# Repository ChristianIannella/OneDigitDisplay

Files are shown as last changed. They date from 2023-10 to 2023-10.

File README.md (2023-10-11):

# OneDigitDisplay
I2C interface for 7 segment LCD

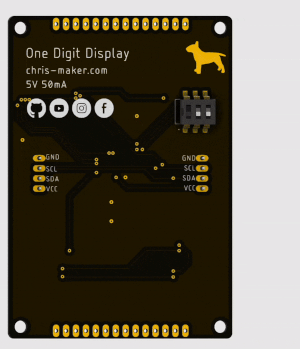
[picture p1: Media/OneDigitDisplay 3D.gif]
OneDigitDisplay Iannella Christian


<picture><picture>

Con One Digit Display puoi controllare [questi](https://github.com/ChristianIannella/OneDigitDisplay/blob/main/Media/7%20segment%20lcd.png) LCD a 7 segmenti dall'aspetto in po' vintage semplicemente con interfaccia I2C, quindi con solo due fili!

Il modulo lavora a 5V. Tramite la porta ICSP è possibile modificare o aggiornare il firmware. Ecco il mio programmatore [ICSP](https://www.tindie.com/products/30806/)

# I2C COMMAND

Ecco la lista completa dei comandi.

| First byte | Second byte | Symbol|
| ---| ---| ---|
|32 | 0 | Space |
|48 |(0 or 1) | 0 |
|49 |(0 or 1) | 1  |
|51 |(0 or 1) | 2 | 
|50 |(0 or 1) | 3|
|52 |(0 or 1) | 4|
|53 |(0 or 1) | 5|
|54 |(0 or 1) | 6|
|55 |(0 or 1) | 7|
|56 |(0 or 1) | 8|
|57 |(0 or 1) | 9|
|10 | 0 | Erase|
|46 | 0 | .|
|45 |(0 or 1) | -|
|20 |(0 or 1) | ˚|
|65 |(0 or 1) | A|
|98 |(0 or 1) | b|
|99 |(0 or 1) | c|
|67 |(0 or 1) | C|
|100 |(0 or 1) | d|
|69 |(0 or 1) | E|
|70 |(0 or 1) | F|
|72 |(0 or 1) | H|
|73 |(0 or 1) | I|
|76 |(0 or 1) | L|
|79 |(0 or 1) | O|
|80 |(0 or 1) | P|
|83 |(0 or 1) | S|
|85 |(0 or 1) | U|
|117 |(0 or 1) | u|
|27 |(0 or 1) |  Segment a|
|28 |(0 or 1) |  Segment b|
|29 |(0 or 1) |  Segment c|
|30 |(0 or 1) |  Segment d|
|31 |(0 or 1) |  Segment e|
|40 |(0 or 1) |  Segment f|
|33 |(0 or 1) |  Segment g|
|34 |(1 to 7) |  DP blink and speed|
|35 |(0 or 1) |  DP stop|
|36 |(0 to 255) |  Background color HSV | 
|37 |(0 to 255) |  Backlight brightness|
|38 |(0 to 255) |  Rainbow effec, default speed 0|
|39 | 0 |  Erase all|

Ogni comando è formato da due Byte, il primo indica la funzione da eseguire e il secondo è un parametro che cambia a seconda della funzione.

Nel di comnadi che stampano caratteri o numeri il parametro puo valere `0`o `1`, `1` attiverà anche il DP `0` no.
I comandi per stampare i caratteri in oltre seguono il codice ASCII.

```
  address = 0
  command[0] = 65;
  command[1] = 1;
  Wire.beginTransmission(address);
  Wire.write(command, sizeof command);
  Wire.endTransmission();
```

L'esempio sopra stamperà la lettera "A" e accenderà il DP del display con indirizzo 0.

Il comando `10` (`erase`) pulisce il display ma lascia attive le altre fuzioni tiopo retroilluminazione ecc. Non necessita di parametri aggiuntivi.

Il comando `34` (`DP blink`) farà lampeggiare il DP con una velocità compresa tra 100 ms e 2s

|Secon Byte|Velocità|
|---|---|
|0|100ms|
|1|200ms|
|2|300ms|
|3|400ms|
|4|500ms|
|5|1000ms|
|6|1500ms|
|7|2000ms|

Esempio:

```
  address = 0
  command[0] = 34;
  command[1] = 4;
  Wire.beginTransmission(address);
  Wire.write(command, sizeof command);
  Wire.endTransmission();
```

Il comando `35` (`DP stop`) blocca il lampeggio del DP e col secondo Byte si puo' decidere se tenerlo acceso o spento.

Il comando `36` serve per cambiare il colore della retroilluminazone tramite il parametro che va da `0` a `255`

Il comando `37` serve per cambiare la luminosità il parametro che va da `0` a `255`

Il comando `38` (`rainbow`) avvia un effetto di colori casuali che cambiano piu' o meno velocemente in base al secondo Byte. Per interrompere l'effetto basta cambiare colore o con il comando `erase_all`.

Il comando `39` fa quello che fa `erase` ma questa volta blocca anche tutte le funzioni attive come `DP blink` o `rainbow`

Il comando `46` mostra il DP, non necessita di parametri.

# I2C ADDRESS
Per indirizzare il display sul retro ci sono 3 dip switch quindi 8 indirizzi possibili, assicurati di dare l'indirizzo desiderato prima di alimentare la scheda.

Nel caso hai bisogno di cambiare indirizzo assicurati di spegnere e riaccendere la schheda dopo averlo cambiato.

# I2C EXAMPLE

```
#include <Wire.h>

int address = 0;
byte command[2];

void setup()
{
  Wire.begin();
  delay(100);

  command[0] = 39; // Erase All Command 
  command[1] = 0;
  Wire.beginTransmission(address);
  Wire.write(command, sizeof command);
  Wire.endTransmission();

  command[0] = 37; // Rainbow
  command[1] = 50;
  Wire.beginTransmission(address);
  Wire.write(command, sizeof command);
  Wire.endTransmission();  
}

void loop(){
}
```

[Esempio completo](https://github.com/ChristianIannella/OneDigitDisplay/tree/main/Example)

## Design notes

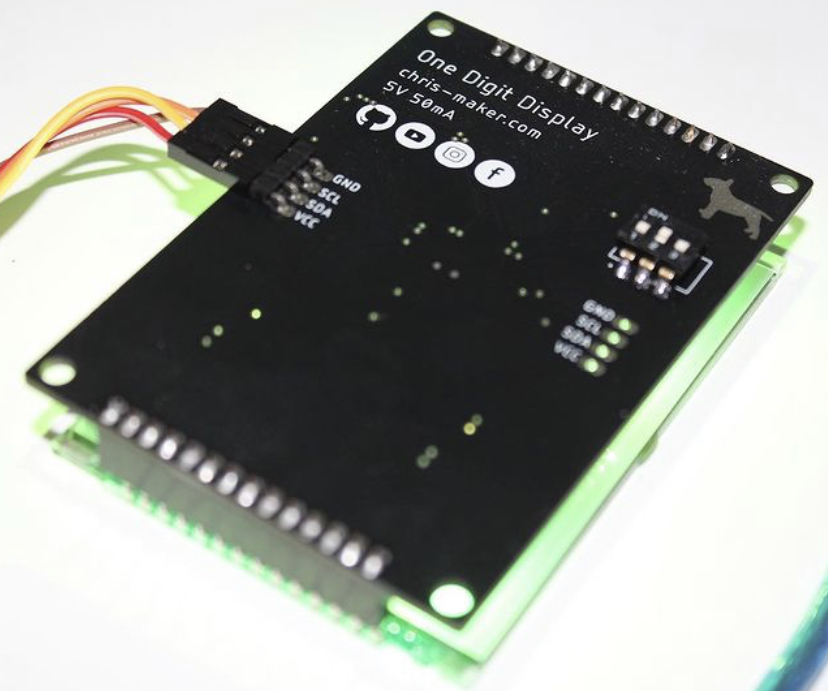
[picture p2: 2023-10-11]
Media/Rear view.jpg

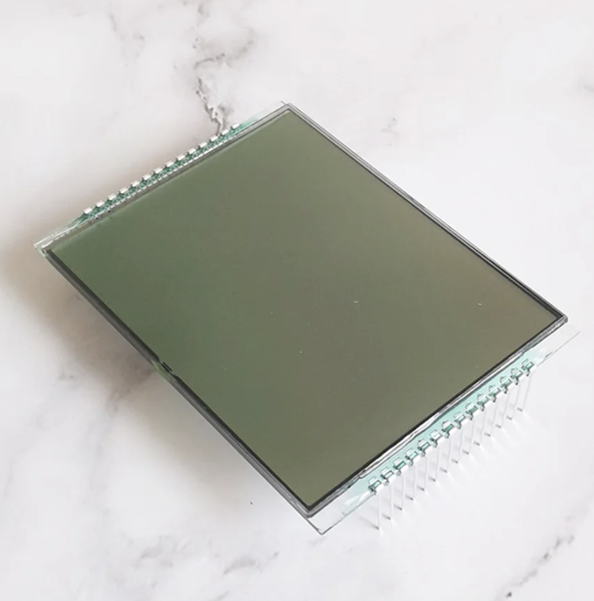
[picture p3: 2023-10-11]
Media/7 segment lcd.png

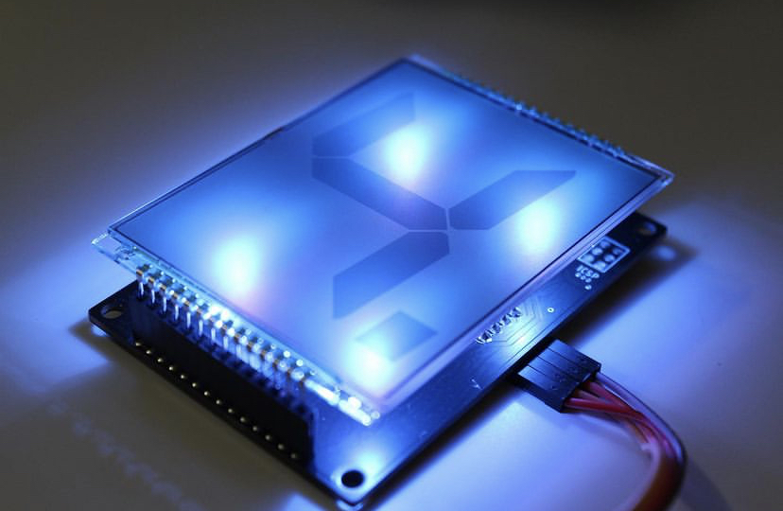
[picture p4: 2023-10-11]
Media/Front view.jpg

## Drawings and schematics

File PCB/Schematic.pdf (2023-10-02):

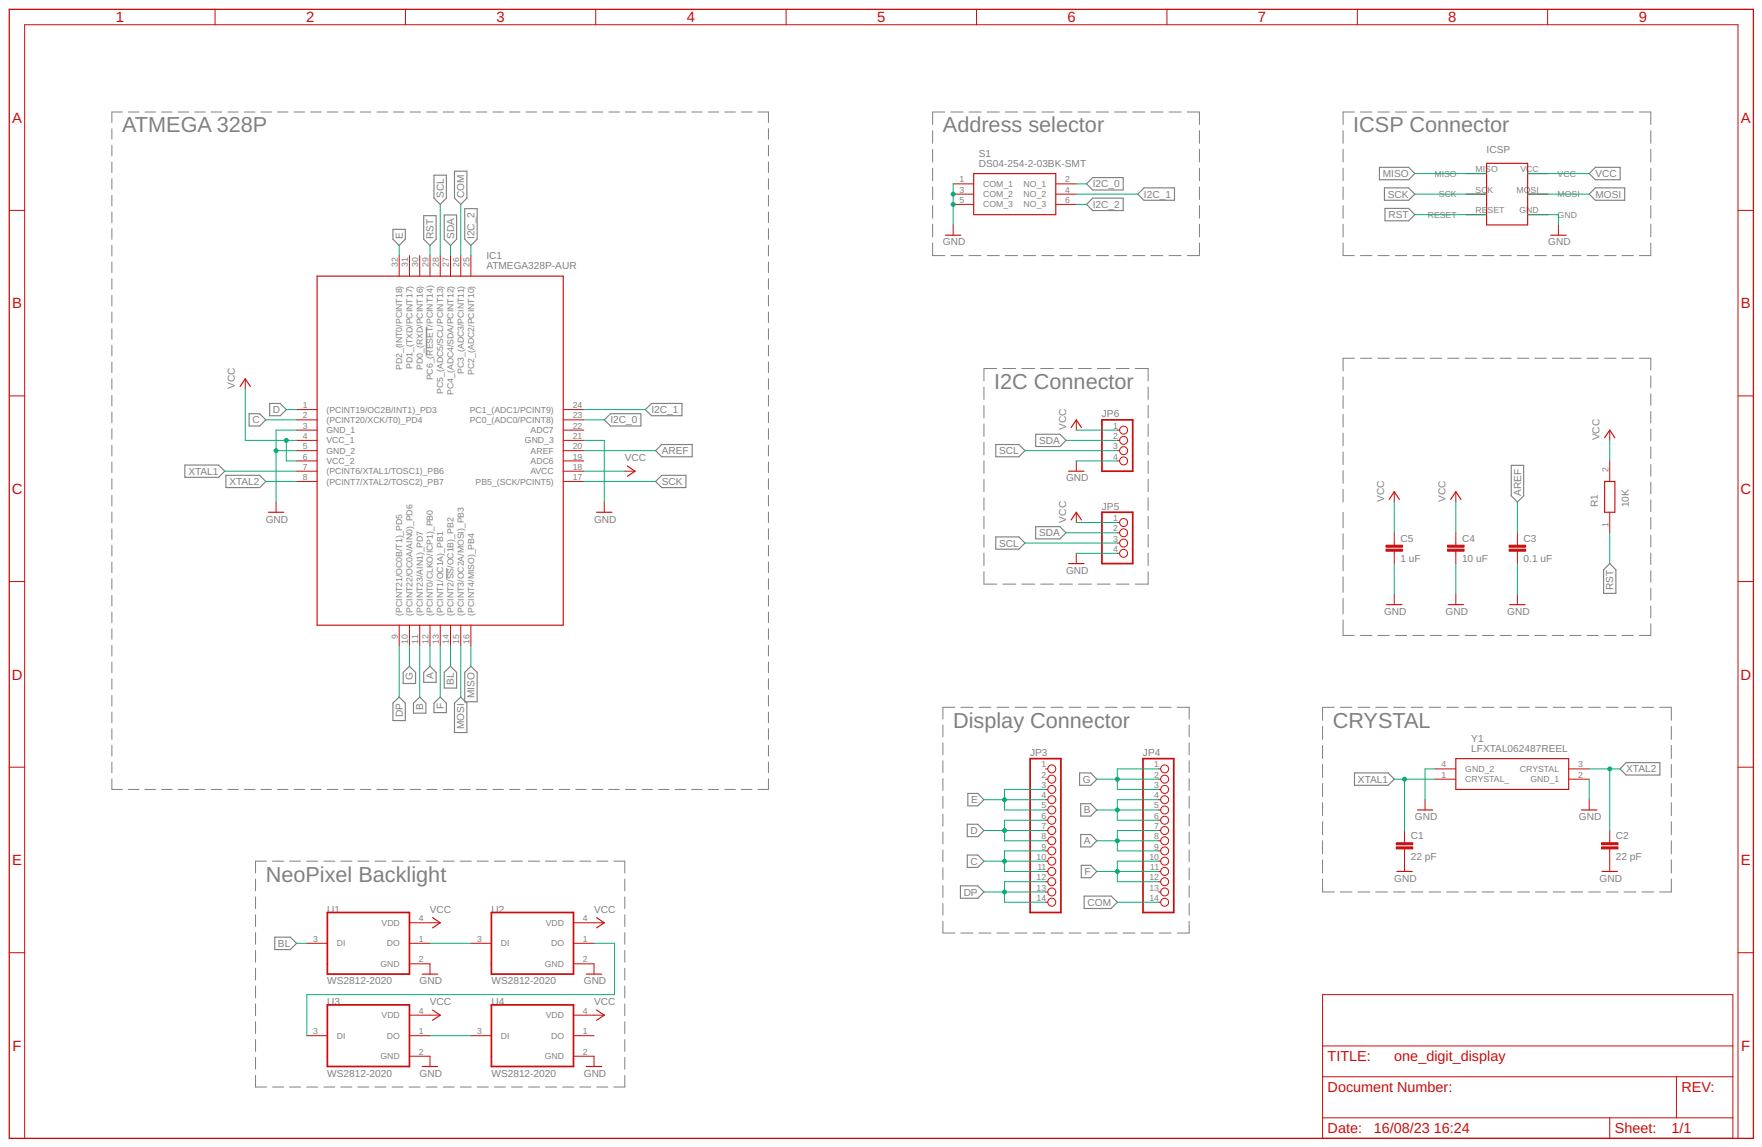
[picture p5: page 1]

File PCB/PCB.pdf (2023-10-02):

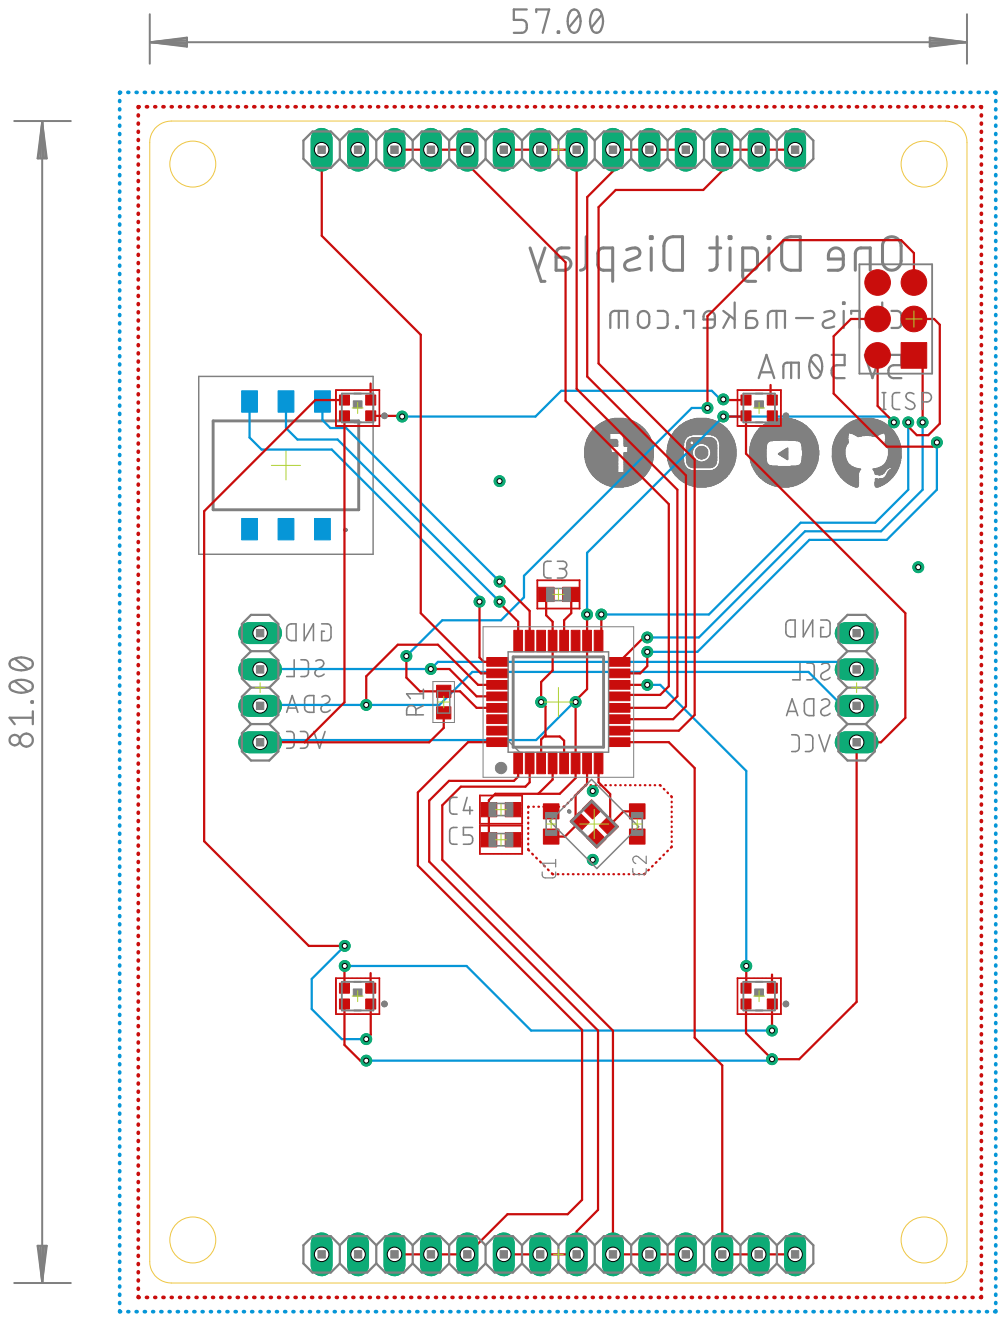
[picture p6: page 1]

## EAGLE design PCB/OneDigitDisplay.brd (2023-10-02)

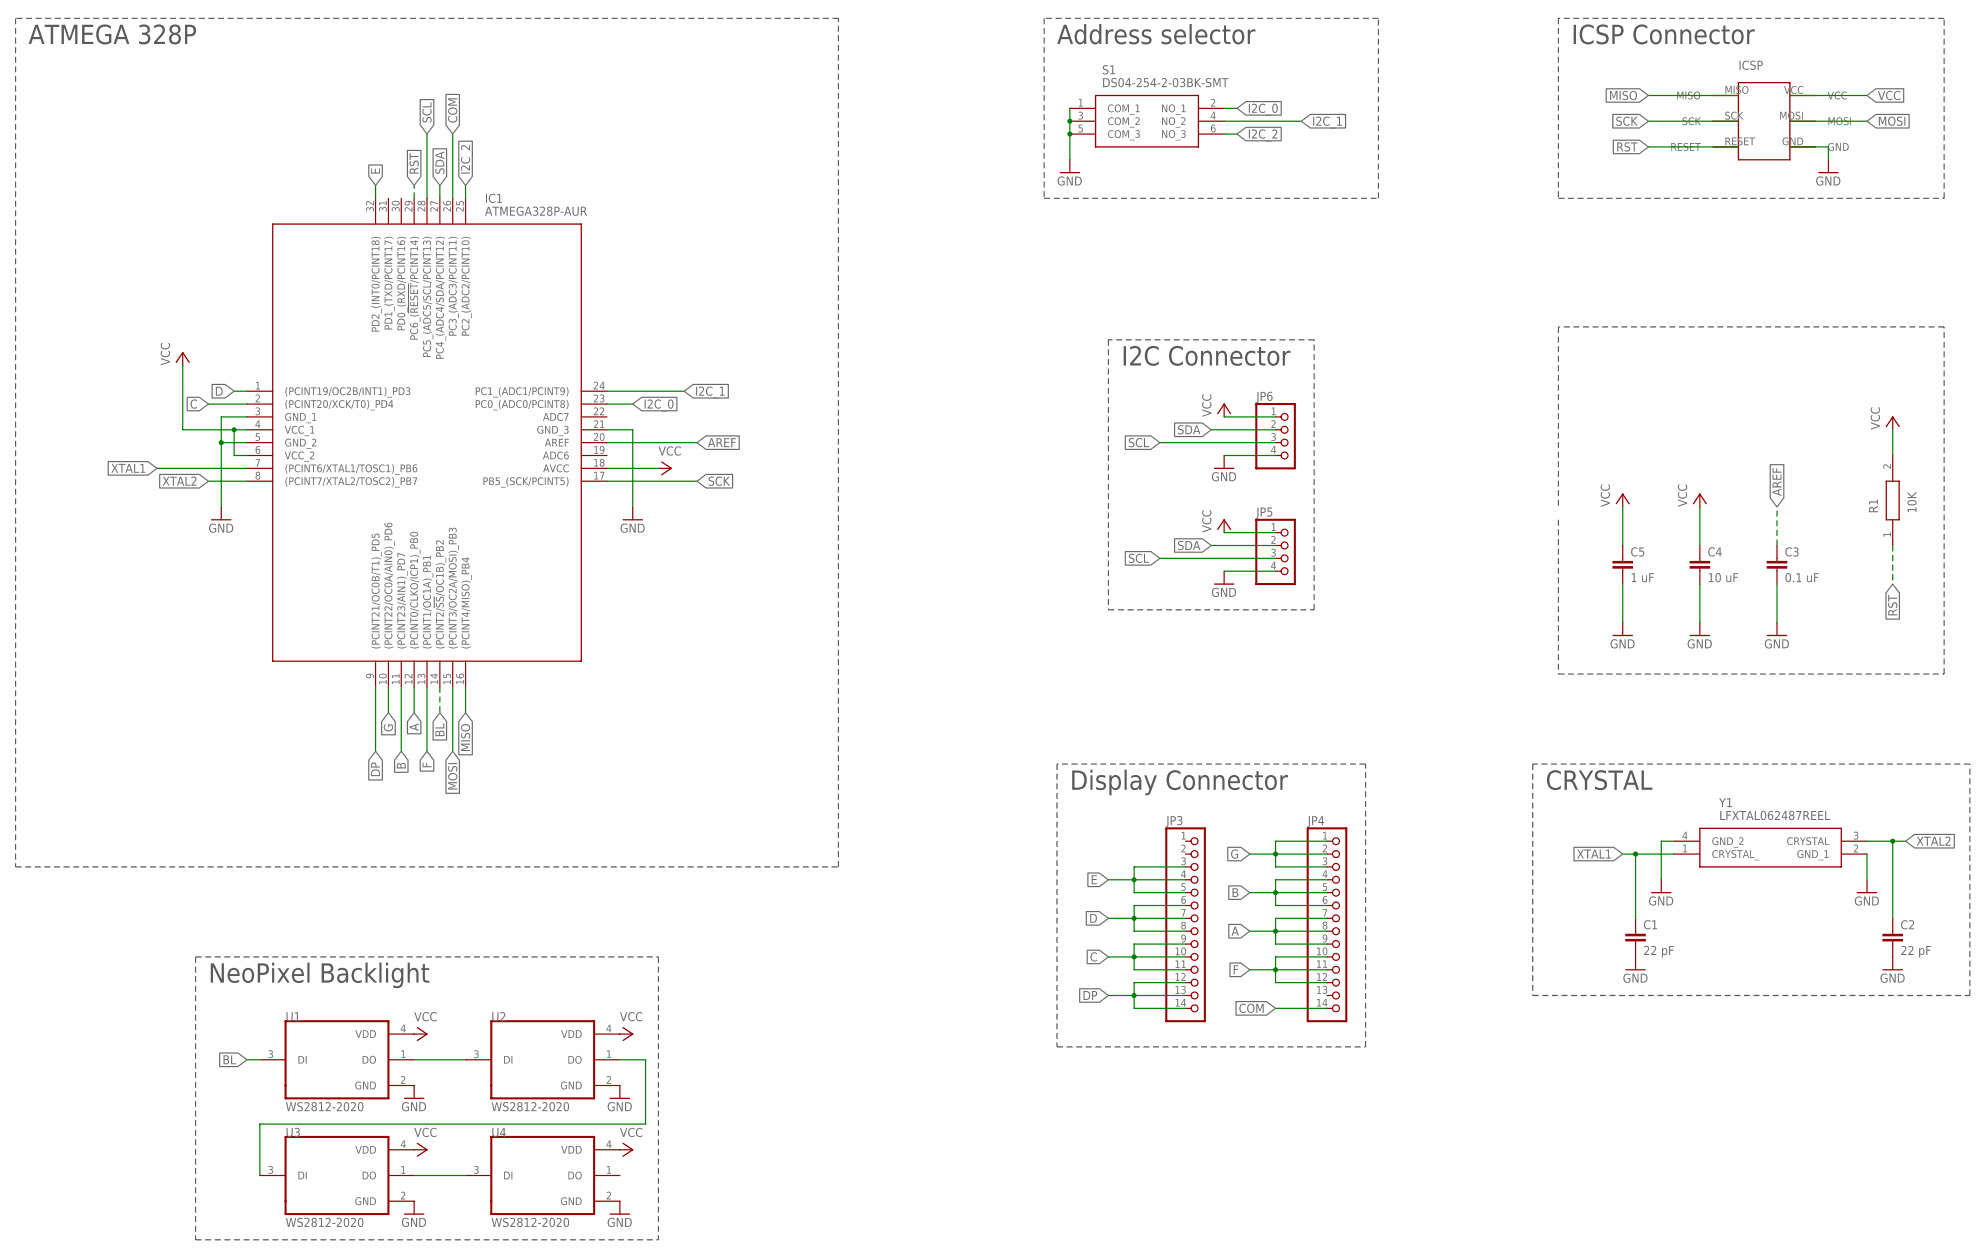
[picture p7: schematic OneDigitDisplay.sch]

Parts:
C1, C2: 22 pF; C0603K
C3: 0.1 uF; C0603
C4: 10 uF; C0603
C5: 1 uF; C0603
IC1: ATMEGA328P-AUR; QFP80P900X900X120-32N
JP3, JP4: PINHD-1X14; 1X14
JP5, JP6: PINHD-1X4; 1X04
R1: 10K; RESC1608X55N
S1: DS04-254-2-03BK-SMT; DS04254203BKSMT
U1, U2, U3, U4: WS2812-2020; LED_WS2812-2020
U$1: 6PINICSP
Y1: LFXTAL062487REEL

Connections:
A: IC1.12 ((PCINT0/CLKO/ICP1)_PB0), JP4.7, JP4.8, JP4.9
AREF: C3.1, IC1.20 (AREF)
B: IC1.11 ((PCINT23/AIN1)_PD7), JP4.4, JP4.5, JP4.6
BL: IC1.14 ((PCINT2/!SS!/OC1B)_PB2), U1.3 (DI)
C: IC1.2 ((PCINT20/XCK/T0)_PD4), JP3.9, JP3.10, JP3.11
COM: IC1.26 (PC3_(ADC3/PCINT11)), JP4.14
D: IC1.1 ((PCINT19/OC2B/INT1)_PD3), JP3.6, JP3.7, JP3.8
DP: IC1.9 ((PCINT21/OC0B/T1)_PD5), JP3.12, JP3.13, JP3.14
E: IC1.32 (PD2_(INT0/PCINT18)), JP3.3, JP3.4, JP3.5
F: IC1.13 ((PCINT1/OC1A)_PB1), JP4.10, JP4.11, JP4.12
G: IC1.10 ((PCINT22/OC0A/AIN0)_PD6), JP4.1, JP4.2, JP4.3
GND: C1.2, C2.2, C3.2, C4.2, C5.2, IC1.3 (GND_1), IC1.5 (GND_2), IC1.21 (GND_3), JP5.4, JP6.4, S1.1 (COM_1), S1.3 (COM_2), S1.5 (COM_3), U1.2 (GND), U2.2 (GND), U3.2 (GND), U4.2 (GND), U$1.GND, Y1.2 (GND_1), Y1.4 (GND_2)
I2C_0: IC1.23 (PC0_(ADC0/PCINT8)), S1.2 (NO_1)
I2C_1: IC1.24 (PC1_(ADC1/PCINT9)), S1.4 (NO_2)
I2C_2: IC1.25 (PC2_(ADC2/PCINT10)), S1.6 (NO_3)
MISO: IC1.16 ((PCINT4/MISO)_PB4), U$1.MISO
MOSI: IC1.15 ((PCINT3/OC2A/MOSI)_PB3), U$1.MOSI
unnamed: U1.1 (DO), U2.3 (DI)
unnamed: U2.1 (DO), U3.3 (DI)
unnamed: U3.1 (DO), U4.3 (DI)
RST: IC1.29 (PC6_(!RESET!/PCINT14)), R1.1, U$1.RESET
SCK: IC1.17 (PB5_(SCK/PCINT5)), U$1.SCK
SCL: IC1.28 (PC5_(ADC5/SCL/PCINT13)), JP5.3, JP6.3
SDA: IC1.27 (PC4_(ADC4/SDA/PCINT12)), JP5.2, JP6.2
VCC: C4.1, C5.1, IC1.4 (VCC_1), IC1.6 (VCC_2), IC1.18 (AVCC), JP5.1, JP6.1, R1.2, U1.4 (VDD), U2.4 (VDD), U3.4 (VDD), U4.4 (VDD), U$1.VCC
XTAL1: C1.1, IC1.7 ((PCINT6/XTAL1/TOSC1)_PB6), Y1.1 (CRYSTAL_)
XTAL2: C2.1, IC1.8 ((PCINT7/XTAL2/TOSC2)_PB7), Y1.3 (CRYSTAL)

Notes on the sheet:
CRYSTAL
NeoPixel Backlight
Address selector
ICSP Connector
Display Connector
I2C Connector
ATMEGA 328P

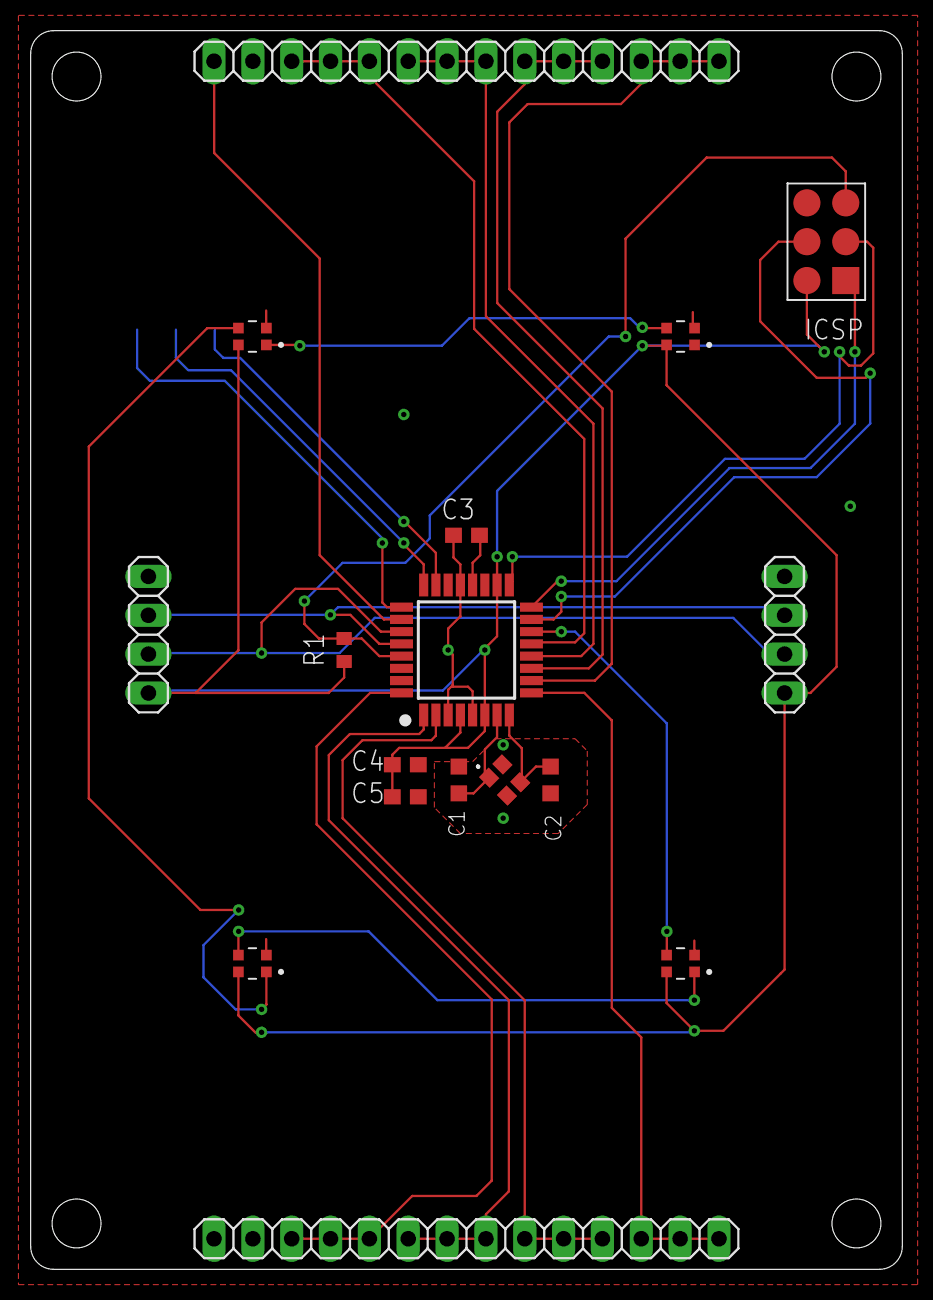
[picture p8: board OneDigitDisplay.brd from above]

Board: 2 copper layers, 57.0 x 81.0 mm, 18 parts (1 on the bottom side), 27 nets.

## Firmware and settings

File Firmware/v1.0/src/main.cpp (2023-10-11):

#include <Arduino.h>
#include <Wire.h>
#include <Adafruit_NeoPixel.h>

#define LED_PIN 10
#define NUM_LED 4
Adafruit_NeoPixel pixel = Adafruit_NeoPixel(NUM_LED, LED_PIN, NEO_GRB + NEO_KHZ800);

#define E 2
#define D 3
#define C 4
#define DP 5
#define G 6
#define B 7
#define A 8
#define F 9
#define COM A3
#define b_l 10
#define DS0 A2
#define DS1 A1
#define DS2 A0

int input_pin[3] = {DS0, DS1, DS2};
byte i2c_address_input[3] = {0};
int i2c_address = 0;

unsigned long previous = 0;
unsigned long previous_dp_blink = 0;
long firstPixelHue = 0;
unsigned long t = 0;

int b_l_value = 0;
bool state = false;
bool dp_blynk_state = false;
unsigned long dp_delay = 20;
bool dp = false;
bool rainbow_state = false;
int rainbow_speed = 0;
int digit = 10;

//                      First byte  Second byte     Symbol
void print_space();     // 32             x          space
void print_zero();      // 48          (0 or 1)        0
void print_one();       // 49          (0 or 1)        1
void print_two();       // 50          (0 or 1)        2
void print_three();     // 51          (0 or 1)        3
void print_four();      // 52          (0 or 1)        4
void print_five();      // 53          (0 or 1)        5
void print_six();       // 54          (0 or 1)        6
void print_seven();     // 55          (0 or 1)        7
void print_eight();     // 56          (0 or 1)        8
void print_nine();      // 57          (0 or 1)        9
void erase();           // 10             x
void show_dp();         // 46             x            .
void print_dash();      // 45          (0 or 1)        -
void print_degrees();   // 20          (0 or 1)        ˚
void print_A();         // 65          (0 or 1)        A
void print_b();         // 98          (0 or 1)        b
void print_c();         // 99          (0 or 1)        c
void print_C();         // 67          (0 or 1)        C
void print_d();         // 100         (0 or 1)        d
void print_E();         // 69          (0 or 1)        E
void print_F();         // 70          (0 or 1)        F
void print_H();         // 72          (0 or 1)        H
void print_I();         // 73          (0 or 1)        I
void print_L();         // 76          (0 or 1)        L
void print_O();         // 79          (0 or 1)        O
void print_P();         // 80          (0 or 1)        P
void print_S();         // 83          (0 or 1)        S
void print_U();         // 85          (0 or 1)        U
void print_u();         // 117         (0 or 1)        u
void print_segment_a(); // 27          (0 or 1)
void print_segment_b(); // 28          (0 or 1)
void print_segment_c(); // 29          (0 or 1)
void print_segment_d(); // 30          (0 or 1)
void print_segment_e(); // 31          (0 or 1)
void print_segment_f(); // 40          (0 or 1)
void print_segment_g(); // 33          (0 or 1)
                        // 34          (1 to 7)         dp blink
                        // 35          (0 or 1)         dp stop
                        // 36          (0 or 255)       Background color
                        // 37          (0 to 255)       Backlight brightness
                        // 38          (1 to 255)       Rainbow
                        // 39             x             erase all

void receiveEvent(int data)
{
  if (Wire.available() == 2)
  {

    int first_byte = Wire.read();
    int second_byte = Wire.read();

    if (first_byte == 34)
    {
      if (digit == 11)
      {
        digit = 10;
      }
      dp_blynk_state = true;
      if (second_byte == 0)
      {
        dp_delay = 100;
      }
      else if (second_byte == 1)
      {
        dp_delay = 200;
      }
      else if (second_byte == 2)
      {
        dp_delay = 300;
      }
      else if (second_byte == 3)
      {
        dp_delay = 400;
      }
      else if (second_byte == 4)
      {
        dp_delay = 500;
      }
      else if (second_byte == 5)
      {
        dp_delay = 1000;
      }
      else if (second_byte == 6)
      {
        dp_delay = 1500;
      }
      else if (second_byte == 7)
      {
        dp_delay = 2000;
      }
    }
    else if (first_byte == 35)
    {
      dp_blynk_state = false;
      if (second_byte == 0)
      {
        dp = false;
      }
      else if (second_byte == 1)
      {
        dp = true;
      }
    }
    else if (first_byte == 36)
    {
      rainbow_state = false;
      for (int i = 0; i <= NUM_LED; i++)
      {
        pixel.setPixelColor(i, pixel.gamma32(pixel.ColorHSV(second_byte * 254)));
      }
      pixel.show();
    }
    else if (first_byte == 37)
    {
      pixel.setBrightness(second_byte);
      pixel.show();
    }
    else if (first_byte == 38)
    {
      rainbow_state = true;
      rainbow_speed = second_byte;
    }
    else if (first_byte == 39)
    {
      rainbow_state = false;
      dp_blynk_state = false;
      dp = false;
      for (int i = 0; i <= NUM_LED; i++)
      {
        pixel.setPixelColor(i,0,0,0);
      }
      pixel.show();
      digit = 10;
    }
    else
    {
      digit = first_byte;
      if (dp_blynk_state == 0)
      {
        dp = second_byte;
      }
    }
  }
}

void requestEvent()
{
}

void setup()
{
  pinMode(COM, OUTPUT);
  pinMode(A, OUTPUT);
  pinMode(B, OUTPUT);
  pinMode(C, OUTPUT);
  pinMode(D, OUTPUT);
  pinMode(E, OUTPUT);
  pinMode(F, OUTPUT);
  pinMode(G, OUTPUT);
  pinMode(DP, OUTPUT);
  pinMode(b_l, OUTPUT);
  pinMode(DS0, INPUT_PULLUP);
  pinMode(DS1, INPUT_PULLUP);
  pinMode(DS2, INPUT_PULLUP);

  digitalWrite(A, LOW);
  digitalWrite(B, LOW);
  digitalWrite(B, LOW);
  digitalWrite(C, LOW);
  digitalWrite(D, LOW);
  digitalWrite(E, LOW);
  digitalWrite(F, LOW);
  digitalWrite(G, LOW);
  digitalWrite(DP, LOW);
  digitalWrite(COM, LOW);
  analogWrite(b_l, LOW);

  for (int a = 0; a < 3; a++)
  {
    i2c_address_input[a] = !digitalRead(input_pin[a]);
    i2c_address = i2c_address * 2 + i2c_address_input[a];
  }

  Wire.begin(i2c_address);
  Wire.onReceive(receiveEvent);
  Wire.onRequest(requestEvent);

  pixel.begin();
  pixel.clear();
  pixel.show();
}

void loop()
{
  unsigned long current_dp_blink = millis();
  unsigned long current = millis();

  raimbow();

  if (dp_blynk_state == true)
  {
    if (current_dp_blink - previous_dp_blink >= dp_delay)
    {
      previous_dp_blink = current_dp_blink;
      dp = !dp;
    }
  }

  if (current - previous >= 5)
  {
    previous = current;
    state = !state;
    digitalWrite(COM, state);

    if (digit == 48)
    {
      print_zero();
    }
    else if (digit == 32)
    {
      print_space();
    }
    else if (digit == 49)
    {
      print_one();
    }
    else if (digit == 50)
    {
      print_two();
    }
    else if (digit == 51)
    {
      print_three();
    }
    else if (digit == 52)
    {
      print_four();
    }
    else if (digit == 53)
    {
      print_five();
    }
    else if (digit == 54)
    {
      print_six();
    }
    else if (digit == 55)
    {
      print_seven();
    }
    else if (digit == 56)
    {
      print_eight();
    }
    else if (digit == 57)
    {
      print_nine();
    }
    else if (digit == 10)
    {
      erase();
    }
    else if (digit == 46)
    {
      show_dp();
    }
    else if (digit == 45)
    {
      print_dash();
    }
    else if (digit == 20)
    {
      print_degrees();
    }
    else if (digit == 65)
    {
      print_A();
    }
    else if (digit == 98)
    {
      print_b();
    }
    else if (digit == 99)
    {
      print_c();
    }
    else if (digit == 67)
    {
      print_C();
    }
    else if (digit == 100)
    {
      print_d();
    }
    else if (digit == 69)
    {
      print_E();
    }
    else if (digit == 70)
    {
      print_F();
    }
    else if (digit == 72)
    {
      print_H();
    }
    else if (digit == 73)
    {
      print_I();
    }
    else if (digit == 76)
    {
      print_L();
    }
    else if (digit == 79)
    {
      print_O();
    }
    else if (digit == 80)
    {
      print_P();
    }
    else if (digit == 83)
    {
      print_S();
    }
    else if (digit == 85)
    {
      print_U();
    }
    else if (digit == 117)
    {
      print_u();
    }
    else if (digit == 27)
    {
      print_segment_a();
    }
    else if (digit == 28)
    {
      print_segment_b();
    }
    else if (digit == 29)
    {
      print_segment_c();
    }
    else if (digit == 30)
    {
      print_segment_d();
    }
    else if (digit == 31)
    {
      print_segment_e();
    }
    else if (digit == 40)
    {
      print_segment_f();
    }
    else if (digit == 33)
    {
      print_segment_g();
    }
  }
}
void print_space()
{
  digitalWrite(A, state);
  digitalWrite(B, state);
  digitalWrite(C, state);
  digitalWrite(D, state);
  digitalWrite(E, state);
  digitalWrite(F, state);
  digitalWrite(G, state);
  digitalWrite(DP, state);
}
void print_zero()
{
  digitalWrite(A, !state);
  digitalWrite(B, !state);
  digitalWrite(C, !state);
  digitalWrite(D, !state);
  digitalWrite(E, !state);
  digitalWrite(F, !state);
  digitalWrite(G, state);
  if (dp == true)
  {
    digitalWrite(DP, !state);
  }
  else
  {
    digitalWrite(DP, state);
  }
}
void print_one()
{
  digitalWrite(A, state);
  digitalWrite(B, !state);
  digitalWrite(C, !state);
  digitalWrite(D, state);
  digitalWrite(E, state);
  digitalWrite(F, state);
  digitalWrite(G, state);
  if (dp == true)
  {
    digitalWrite(DP, !state);
  }
  else
  {
    digitalWrite(DP, state);
  }
}
void print_two()
{
  digitalWrite(A, !state);
  digitalWrite(B, !state);
  digitalWrite(C, state);
  digitalWrite(D, !state);
  digitalWrite(E, !state);
  digitalWrite(F, state);
  digitalWrite(G, !state);
  if (dp == true)
  {
    digitalWrite(DP, !state);
  }
  else
  {
    digitalWrite(DP, state);
  }
}
void print_three()
{
  digitalWrite(A, !state);
  digitalWrite(B, !state);
  digitalWrite(C, !state);
  digitalWrite(D, !state);
  digitalWrite(E, state);
  digitalWrite(F, state);
  digitalWrite(G, !state);
  if (dp == true)
  {
    digitalWrite(DP, !state);
  }
  else
  {
    digitalWrite(DP, state);
  }
}
void print_four()
{
  digitalWrite(A, state);
  digitalWrite(B, !state);
  digitalWrite(C, !state);
  digitalWrite(D, state);
  digitalWrite(E, state);
  digitalWrite(F, !state);
  digitalWrite(G, !state);
  if (dp == true)
  {
    digitalWrite(DP, !state);
  }
  else
  {
    digitalWrite(DP, state);
  }
}
void print_five()
{
  digitalWrite(A, !state);
  digitalWrite(B, state);
  digitalWrite(C, !state);
  digitalWrite(D, !state);
  digitalWrite(E, state);
  digitalWrite(F, !state);
  digitalWrite(G, !state);
  if (dp == true)
  {
    digitalWrite(DP, !state);
  }
  else
  {
    digitalWrite(DP, state);
  }
}
void print_six()
{
  digitalWrite(A, !state);
  digitalWrite(B, state);
  digitalWrite(C, !state);
  digitalWrite(D, !state);
  digitalWrite(E, !state);
  digitalWrite(F, !state);
  digitalWrite(G, !state);
  if (dp == true)
  {
    digitalWrite(DP, !state);
  }
  else
  {
    digitalWrite(DP, state);
  }
}
void print_seven()
{
  digitalWrite(A, !state);
  digitalWrite(B, !state);
  digitalWrite(C, !state);
  digitalWrite(D, state);
  digitalWrite(E, state);
  digitalWrite(F, state);
  digitalWrite(G, state);
  if (dp == true)
  {
    digitalWrite(DP, !state);
  }
  else
  {
    digitalWrite(DP, state);
  }
}
void print_eight()
{
  digitalWrite(A, !state);
  digitalWrite(B, !state);
  digitalWrite(C, !state);
  digitalWrite(D, !state);
  digitalWrite(E, !state);
  digitalWrite(F, !state);
  digitalWrite(G, !state);
  if (dp == true)
  {
    digitalWrite(DP, !state);
  }
  else
  {
    digitalWrite(DP, state);
  }
}
void print_nine()
{
  digitalWrite(A, !state);
  digitalWrite(B, !state);
  digitalWrite(C, !state);
  digitalWrite(D, !state);
  digitalWrite(E, state);
  digitalWrite(F, !state);
  digitalWrite(G, !state);
  if (dp == true)
  {
    digitalWrite(DP, !state);
  }
  else
  {
    digitalWrite(DP, state);
  }
}
void erase()
{
  digitalWrite(A, state);
  digitalWrite(B, state);
  digitalWrite(C, state);
  digitalWrite(D, state);
  digitalWrite(E, state);
  digitalWrite(F, state);
  digitalWrite(G, state);
  digitalWrite(DP, state);
  if (dp == true)
  {
    digitalWrite(DP, !state);
  }
  else
  {
    digitalWrite(DP, state);
  }
}
void show_dp()
{
  dp = true;
  digitalWrite(A, state);
  digitalWrite(B, state);
  digitalWrite(C, state);
  digitalWrite(D, state);
  digitalWrite(E, state);
  digitalWrite(F, state);
  digitalWrite(G, state);
  if (dp == true)
  {
    digitalWrite(DP, !state);
  }
  else
  {
    digitalWrite(DP, state);
  }
}
void print_dash()
{
  digitalWrite(A, state);
  digitalWrite(B, state);
  digitalWrite(C, state);
  digitalWrite(D, state);
  digitalWrite(E, state);
  digitalWrite(F, state);
  digitalWrite(G, !state);
  if (dp == true)
  {
    digitalWrite(DP, !state);
  }
  else
  {
    digitalWrite(DP, state);
  }
}
void print_degrees()
{
  digitalWrite(A, !state);
  digitalWrite(B, !state);
  digitalWrite(C, state);
  digitalWrite(D, state);
  digitalWrite(E, state);
  digitalWrite(F, !state);
  digitalWrite(G, !state);
  if (dp == true)
  {
    digitalWrite(DP, !state);
  }
  else
  {
    digitalWrite(DP, state);
  }
}
void print_A()
{
  digitalWrite(A, !state);
  digitalWrite(B, !state);
  digitalWrite(C, !state);
  digitalWrite(D, state);
  digitalWrite(E, !state);
  digitalWrite(F, !state);
  digitalWrite(G, !state);
  if (dp == true)
  {
    digitalWrite(DP, !state);
  }
  else
  {
    digitalWrite(DP, state);
  }
}
void print_b()
{
  digitalWrite(A, state);
  digitalWrite(B, state);
  digitalWrite(C, !state);
  digitalWrite(D, !state);
  digitalWrite(E, !state);
  digitalWrite(F, !state);
  digitalWrite(G, !state);
  if (dp == true)
  {
    digitalWrite(DP, !state);
  }
  else
  {
    digitalWrite(DP, state);
  }
}
void print_c()
{
  digitalWrite(A, state);
  digitalWrite(B, state);
  digitalWrite(C, state);
  digitalWrite(D, !state);
  digitalWrite(E, !state);
  digitalWrite(F, state);
  digitalWrite(G, !state);
  if (dp == true)
  {
    digitalWrite(DP, !state);
  }
  else
  {
    digitalWrite(DP, state);
  }
}
void print_C()
{
  digitalWrite(A, !state);
  digitalWrite(B, state);
  digitalWrite(C, state);
  digitalWrite(D, !state);
  digitalWrite(E, !state);
  digitalWrite(F, !state);
  digitalWrite(G, state);
  if (dp == true)
  {
    digitalWrite(DP, !state);
  }
  else
  {
    digitalWrite(DP, state);
  }
}
void print_d()
{
  digitalWrite(A, state);
  digitalWrite(B, !state);
  digitalWrite(C, !state);
  digitalWrite(D, !state);
  digitalWrite(E, !state);
  digitalWrite(F, state);
  digitalWrite(G, !state);
  if (dp == true)
  {
    digitalWrite(DP, !state);
  }
  else
  {
    digitalWrite(DP, state);
  }
}
void print_E()
{
  digitalWrite(A, !state);
  digitalWrite(B, state);
  digitalWrite(C, state);
  digitalWrite(D, !state);
  digitalWrite(E, !state);
  digitalWrite(F, !state);
  digitalWrite(G, !state);
  if (dp == true)
  {
    digitalWrite(DP, !state);
  }
  else
  {
    digitalWrite(DP, state);
  }
}
void print_F()
{
  digitalWrite(A, !state);
  digitalWrite(B, state);
  digitalWrite(C, state);
  digitalWrite(D, state);
  digitalWrite(E, !state);
  digitalWrite(F, !state);
  digitalWrite(G, !state);
  if (dp == true)
  {
    digitalWrite(DP, !state);
  }
  else
  {
    digitalWrite(DP, state);
  }
}
void print_H()
{
  digitalWrite(A, state);
  digitalWrite(B, !state);
  digitalWrite(C, !state);
  digitalWrite(D, state);
  digitalWrite(E, !state);
  digitalWrite(F, !state);
  digitalWrite(G, !state);
  if (dp == true)
  {
    digitalWrite(DP, !state);
  }
  else
  {
    digitalWrite(DP, state);
  }
}
void print_I()
{
  digitalWrite(A, state);
  digitalWrite(B, state);
  digitalWrite(C, state);
  digitalWrite(D, state);
  digitalWrite(E, !state);
  digitalWrite(F, !state);
  digitalWrite(G, state);
  if (dp == true)
  {
    digitalWrite(DP, !state);
  }
  else
  {
    digitalWrite(DP, state);
  }
}
void print_L()
{
  digitalWrite(A, state);
  digitalWrite(B, state);
  digitalWrite(C, state);
  digitalWrite(D, !state);
  digitalWrite(E, !state);
  digitalWrite(F, !state);
  digitalWrite(G, state);
  if (dp == true)
  {
    digitalWrite(DP, !state);
  }
  else
  {
    digitalWrite(DP, state);
  }
}
void print_O()
{
  digitalWrite(A, !state);
  digitalWrite(B, !state);
  digitalWrite(C, !state);
  digitalWrite(D, !state);
  digitalWrite(E, !state);
  digitalWrite(F, !state);
  digitalWrite(G, state);
  if (dp == true)
  {
    digitalWrite(DP, !state);
  }
  else
  {
    digitalWrite(DP, state);
  }
}
void print_P()
{
  digitalWrite(A, !state);
  digitalWrite(B, !state);
  digitalWrite(C, state);
  digitalWrite(D, state);
  digitalWrite(E, !state);
  digitalWrite(F, !state);
  digitalWrite(G, !state);
  if (dp == true)
  {
    digitalWrite(DP, !state);
  }
  else
  {
    digitalWrite(DP, state);
  }
}
void print_S()
{
  digitalWrite(A, !state);
  digitalWrite(B, state);
  digitalWrite(C, !state);
  digitalWrite(D, !state);
  digitalWrite(E, state);
  digitalWrite(F, !state);
  digitalWrite(G, !state);
  if (dp == true)
  {
    digitalWrite(DP, !state);
  }
  else
  {
    digitalWrite(DP, state);
  }
}
void print_U()
{
  digitalWrite(A, state);
  digitalWrite(B, !state);
  digitalWrite(C, !state);
  digitalWrite(D, !state);
  digitalWrite(E, !state);
  digitalWrite(F, !state);
  digitalWrite(G, state);
  if (dp == true)
  {
    digitalWrite(DP, !state);
  }
  else
  {
    digitalWrite(DP, state);
  }
}
void print_u()
{
  digitalWrite(A, state);
  digitalWrite(B, state);
  digitalWrite(C, !state);
  digitalWrite(D, !state);
  digitalWrite(E, !state);
  digitalWrite(F, state);
  digitalWrite(G, state);
  if (dp == true)
  {
    digitalWrite(DP, !state);
  }
  else
  {
    digitalWrite(DP, state);
  }
}
void print_segment_a()
{
  digitalWrite(A, !state);
  digitalWrite(B, state);
  digitalWrite(C, state);
  digitalWrite(D, state);
  digitalWrite(E, state);
  digitalWrite(F, state);
  digitalWrite(G, state);
  if (dp == true)
  {
    digitalWrite(DP, !state);
  }
  else
  {
    digitalWrite(DP, state);
  }
}
void print_segment_b()
{
  digitalWrite(A, state);
  digitalWrite(B, !state);
  digitalWrite(C, state);
  digitalWrite(D, state);
  digitalWrite(E, state);
  digitalWrite(F, state);
  digitalWrite(G, state);
  if (dp == true)
  {
    digitalWrite(DP, !state);
  }
  else
  {
    digitalWrite(DP, state);
  }
}
void print_segment_c()
{
  digitalWrite(A, state);
  digitalWrite(B, state);
  digitalWrite(C, !state);
  digitalWrite(D, state);
  digitalWrite(E, state);
  digitalWrite(F, state);
  digitalWrite(G, state);
  if (dp == true)
  {
    digitalWrite(DP, !state);
  }
  else
  {
    digitalWrite(DP, state);
  }
}
void print_segment_d()
{
  digitalWrite(A, state);
  digitalWrite(B, state);
  digitalWrite(C, state);
  digitalWrite(D, !state);
  digitalWrite(E, state);
  digitalWrite(F, state);
  digitalWrite(G, state);
  if (dp == true)
  {
    digitalWrite(DP, !state);
  }
  else
  {
    digitalWrite(DP, state);
  }
}
void print_segment_e()
{
  digitalWrite(A, state);
  digitalWrite(B, state);
  digitalWrite(C, state);
  digitalWrite(D, state);
  digitalWrite(E, !state);
  digitalWrite(F, state);
  digitalWrite(G, state);
  if (dp == true)
  {
    digitalWrite(DP, !state);
  }
  else
  {
    digitalWrite(DP, state);
  }
}
void print_segment_f()
{
  digitalWrite(A, state);
  digitalWrite(B, state);
  digitalWrite(C, state);
  digitalWrite(D, state);
  digitalWrite(E, state);
  digitalWrite(F, !state);
  digitalWrite(G, state);
  if (dp == true)
  {
    digitalWrite(DP, !state);
  }
  else
  {
    digitalWrite(DP, state);
  }
}
void print_segment_g()
{
  digitalWrite(A, state);
  digitalWrite(B, state);
  digitalWrite(C, state);
  digitalWrite(D, state);
  digitalWrite(E, state);
  digitalWrite(F, state);
  digitalWrite(G, !state);
  if (dp == true)
  {
    digitalWrite(DP, !state);
  }
  else
  {
    digitalWrite(DP, state);
  }
}

void raimbow()
{
  if (rainbow_state == true)
  {
    if (millis() > t + 1+(1*rainbow_speed))
    {
      t = millis();
      for (int i = 0; i < pixel.numPixels(); i++)
      {
        int pixelHue = firstPixelHue  + (i * 65536L / pixel.numPixels());
        // int pixelHue = firstPixelHue + (65536L / ring.numPixels());
        pixel.setPixelColor(i, pixel.gamma32(pixel.ColorHSV(pixelHue)));
      }
      pixel.show();
      if (firstPixelHue > 5 * 65536)
      {
        firstPixelHue = 1000 * i2c_address;
      }
      firstPixelHue += 256;
    }
  }
}

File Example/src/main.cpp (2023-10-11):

#include <Arduino.h>
#include <Wire.h>

byte address[4] = {1, 2, 3, 4};
byte command[2];
byte numbers[10][2] = {{48, 0},
                       {49, 0},
                       {50, 0},
                       {51, 0},
                       {52, 0},
                       {53, 0},
                       {54, 0},
                       {55, 0},
                       {56, 0},
                       {57, 0}};
byte erase[2] = {10, 0};

void print_number(int number_to_stamp, int cursor);
void print_string(char string_to_stamp[], int cursor);
void erase_screen();
void colori();
void bianco();
void rosso();
void rainbow();
void verde();
void print_gradi(int cursore);
void dp_blink(int speed, int cursore);
void dp_stop(int onoff, int cursore);
void animazione();

void setup()
{
  Serial.begin(9600);
  Serial.println("Hello clock");
  Wire.begin();
  delay(100);

  command[0] = 39;
  command[1] = 0;
  for (uint8_t i = 0; i < sizeof address; i++)
  {
    Wire.beginTransmission(address[i]);
    Wire.write(command, sizeof command);
    Wire.endTransmission();
  }
}

void loop()
{
  print_string("CIAO", 0);
  colori();
  delay(2000);
  erase_screen();
  print_gradi(0);
  print_string("23", 1);
  rainbow();
  delay(1000);
  erase_screen();
  bianco();
  for (int i = 0; i < 20; i++)
  {
    print_number(i, 0);
    delay(200);
  }
  delay(200);
  rosso();
  for (int i = 20; i > 0; i--)
  {
    print_number(i, 0);
    delay(200);
  }
  delay(200);
  verde();
  print_string("----", 0);
  delay(1000);
  dp_blink(3, 2);
  print_string("1315", 0);
  rainbow();
  dp_stop(0, 2);
  erase_screen();
  bianco();
  dp_blink(0, 0);
  dp_blink(2, 1);
  dp_blink(4, 2);
  dp_blink(6, 3);
  delay(5000);
  dp_stop(0, 0);
  dp_stop(0, 1);
  dp_stop(0, 2);
  dp_stop(0, 3);
  animazione();
}

void print_number(int number_to_stamp, int cursor)
{

  char array_data[10];
  sprintf(array_data, "%d", number_to_stamp);

  if (number_to_stamp > 9999)
  {
    Serial.println("Overflow");
  }

  else if (number_to_stamp <= 9999)
  {
    erase_screen();
    if (number_to_stamp > 999)
    {
      int index = array_data[0];
      Serial.println(index - 48);
      Wire.beginTransmission(address[3 + cursor]);
      Wire.write(numbers[index - 48], sizeof numbers[index - 48]);
      Wire.endTransmission();

      index = array_data[1];
      Serial.println(index - 48);
      Wire.beginTransmission(address[2 + cursor]);
      Wire.write(numbers[index - 48], sizeof numbers[index - 48]);
      Wire.endTransmission();

      index = array_data[2];
      Serial.println(index - 48);
      Wire.beginTransmission(address[1 + cursor]);
      Wire.write(numbers[index - 48], sizeof numbers[index - 48]);
      Wire.endTransmission();

      index = array_data[3];
      Serial.println(index - 48);
      Wire.beginTransmission(address[0 + cursor]);
      Wire.write(numbers[index - 48], sizeof numbers[index - 48]);
      Wire.endTransmission();
    }
    else if (number_to_stamp > 99)
    {
      Serial.println("3 cifre");
      int index = array_data[0];
      Serial.print(index - 48);
      Wire.beginTransmission(address[2 + cursor]);
      Wire.write(numbers[index - 48], sizeof numbers[index - 48]);
      Wire.endTransmission();

      index = array_data[1];
      Serial.print(index - 48);
      Wire.beginTransmission(address[1 + cursor]);
      Wire.write(numbers[index - 48], sizeof numbers[index - 48]);
      Wire.endTransmission();

      index = array_data[2];
      Serial.print(index - 48);
      Wire.beginTransmission(address[0 + cursor]);
      Wire.write(numbers[index - 48], sizeof numbers[index - 48]);
      Wire.endTransmission();
      Serial.println(" ");
    }

    else if (number_to_stamp > 9)
    {
      int index = array_data[0];
      Wire.beginTransmission(address[1 + cursor]);
      Wire.write(numbers[index - 48], sizeof numbers[index - 48]);
      Wire.endTransmission();

      index = array_data[1];
      Wire.beginTransmission(address[0 + cursor]);
      Wire.write(numbers[index - 48], sizeof numbers[index - 48]);
      Wire.endTransmission();
    }

    else
    {
      int index = array_data[0];
      Wire.beginTransmission(address[0 + cursor]);
      Wire.write(numbers[index - 48], sizeof numbers[index - 48]);
      Wire.endTransmission();
    }
  }
}

void print_string(char string_to_stamp[], int cursor)
{

  for (uint8_t i = 0; i < 4; i++)
  {
    if (string_to_stamp[i] == NULL)
    {
      break;
    }
    command[0] = string_to_stamp[i];
    command[1] = 0;
    Wire.beginTransmission(address[(3 - i) - cursor]);
    Wire.write(command, sizeof command);
    Wire.endTransmission();
  }
}

void erase_screen()
{
  for (uint8_t i = 0; i < sizeof address; i++)
  {
    Wire.beginTransmission(address[i]);
    Wire.write(erase, sizeof erase);
    Wire.endTransmission();
  }
}

void colori()
{
  command[0] = 36;
  command[1] = 255;
  Wire.beginTransmission(address[0]);
  Wire.write(command, sizeof command);
  Wire.endTransmission();
  command[0] = 36;
  command[1] = 210;
  Wire.beginTransmission(address[1]);
  Wire.write(command, sizeof command);
  Wire.endTransmission();
  command[0] = 36;
  command[1] = 120;
  Wire.beginTransmission(address[2]);
  Wire.write(command, sizeof command);
  Wire.endTransmission();
  command[0] = 36;
  command[1] = 50;
  Wire.beginTransmission(address[3]);
  Wire.write(command, sizeof command);
  Wire.endTransmission();
}

void rainbow()
{
  command[0] = 37;
  command[1] = 200;
  for (uint8_t i = 0; i < sizeof address; i++)
  {
    Wire.beginTransmission(address[i]);
    Wire.write(command, sizeof command);
    Wire.endTransmission();
  }
  for (int e = 0; e < 6; e++)
  {
    command[0] = 38;
    command[1] = 1 + (10 * e);
    for (uint8_t i = 0; i < sizeof address; i++)
    {
      Wire.beginTransmission(address[i]);
      Wire.write(command, sizeof command);
      Wire.endTransmission();
    }
    delay(1000);
  }
}

void bianco()
{
  command[0] = 36;
  command[1] = 125;
  for (uint8_t i = 0; i < sizeof address; i++)
  {
    Wire.beginTransmission(address[i]);
    Wire.write(command, sizeof command);
    Wire.endTransmission();
  }
}

void rosso()
{
  command[0] = 36;
  command[1] = 1;
  for (uint8_t i = 0; i < sizeof address; i++)
  {
    Wire.beginTransmission(address[i]);
    Wire.write(command, sizeof command);
    Wire.endTransmission();
  }
}

void verde()
{
  command[0] = 36;
  command[1] = 50;
  for (uint8_t i = 0; i < sizeof address; i++)
  {
    Wire.beginTransmission(address[i]);
    Wire.write(command, sizeof command);
    Wire.endTransmission();
  }
}

void print_gradi(int cursore)
{
  command[0] = 20;
  command[1] = 0;
  Wire.beginTransmission(address[cursore]);
  Wire.write(command, sizeof command);
  Wire.endTransmission();
}

void dp_blink(int speed, int cursore)
{
  command[0] = 34;
  command[1] = speed;
  Wire.beginTransmission(address[cursore]);
  Wire.write(command, sizeof command);
  Wire.endTransmission();
}
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
